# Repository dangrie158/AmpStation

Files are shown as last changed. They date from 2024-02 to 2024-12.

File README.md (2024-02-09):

# Class D Amplifier Project

This project aims to repurpose an old Teufel Decoder Station Case by building a Class D amplifier inside it.

## Introduction

The old Teufel Decoder Station Case has been transformed into a powerful Class D amplifier in this project.

## Features

- Compact design that fits perfectly into the Teufel Decoder Station Case
- High-efficiency Class D amplifier technology
- Excellent audio quality with low distortion
- Multiple input options for versatile connectivity
- Built-in protection circuitry for safe operation

This project is licensed under the [MIT License](LICENSE).

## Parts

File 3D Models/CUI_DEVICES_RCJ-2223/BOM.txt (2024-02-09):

3DX_CUI_DEVICES_Supplier: CUI Devices
3DX_CUI_DEVICES_Description: RCJ-22 Series, Input 1: Red, Input 2: White
3DX_CUI_DEVICES_Model Number: RCJ-2223

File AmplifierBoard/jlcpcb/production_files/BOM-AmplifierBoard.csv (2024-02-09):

Comment | Designator | Footprint | LCSC
10µH | L10,L11,L12,L13,L14,L15,L16,L17,L18,L19,L20,L21,L6,L7,L8,L9 | L_0805_2012Metric_Pad1.15x1.40mm_HandSolder | C1046
30pF | C97 | C_0805_2012Metric_Pad1.18x1.45mm_HandSolder | C107114
22µF | C40 | C_1206_3216Metric_Pad1.33x1.80mm_HandSolder | C12891
470pF | C42,C43,C46,C47 | C_0603_1608Metric_Pad1.08x0.95mm_HandSolder | C1620
18pF | C53,C54 | C_0603_1608Metric_Pad1.08x0.95mm_HandSolder | C1647
33nF | C15,C16 | C_Rect_L7.2mm_W2.5mm_P5.00mm_FKS2_FKP2_MKS2_MKP2 | C1739
100pF | C93,C94,C95,C96 | C_0805_2012Metric_Pad1.18x1.45mm_HandSolder | C1790
0 | R43,R46 | R_0603_1608Metric_Pad0.98x0.95mm_HandSolder | C21189
1k | R47,R48,R49,R50,R51,R52 | R_0603_1608Metric_Pad0.98x0.95mm_HandSolder | C21190
3k3 | R13,R14,R17,R18 | R_0603_1608Metric_Pad0.98x0.95mm_HandSolder | C22978
4k7 | R1,R2,R55,R56 | R_0603_1608Metric_Pad0.98x0.95mm_HandSolder | C23162
680 | R11,R12,R19,R20 | R_0603_1608Metric_Pad0.98x0.95mm_HandSolder | C23228
22 | R21,R22,R23,R24 | R_0603_1608Metric_Pad0.98x0.95mm_HandSolder | C23345
100k | R30,R31,R32,R33,R34,R35,R36,R37,R38,R39,R40,R41,R57,R58 | R_0603_1608Metric_Pad0.98x0.95mm_HandSolder | C25803
10k | R25,R26,R27,R28,R29,R42,R44,R45,R53,R54,R8 | R_0603_1608Metric_Pad0.98x0.95mm_HandSolder | C25804
100nF | C10,C12,C13,C14,C35,C36,C37,C38,C49,C50,C52,C55,C56,C58,C60,C61,C62,C63,C64,C66,C67,C68,C69,C70,C72,C73,C77,C78,C80,C81,C84,C85,C88,C89,C91,C92 | C_0805_2012Metric_Pad1.18x1.45mm_HandSolder | C28233
1µF 50V | C1,C2,C4,C44,C5,C7,C8 | C_0805_2012Metric_Pad1.18x1.45mm_HandSolder | C28323
22k | R7 | R_0603_1608Metric_Pad0.98x0.95mm_HandSolder | C31850
1.8k | R10,R15,R16,R9 | R_0603_1608Metric_Pad0.98x0.95mm_HandSolder | C4177
74HC14 | U17 | SOIC-14_3.9x8.7mm_P1.27mm | C5605
10µF | C83 | CP_EIA-3216-18_Kemet-A_Pad1.58x1.35mm_HandSolder | C7171
LM358 | U16 | SOIC-8_5.23x5.23mm_P1.27mm | C7950
1N4148 | D2,D3 | D_SOD-123 | C81598
12MHz | Y1 | Crystal_SMD_3225-4Pin_3.2x2.5mm_HandSoldering | C9002
~ | H2 | 3.2mm Hole Oblong
~ | H1 | 3.2mm Hole Oblong
~ | H4 | 3.2mm Hole Oblong
~ | H3 | 3.2mm Hole Oblong
1µ | C26 | C_Rect_L10.3mm_W5.0mm_P7.50mm_MKS4
AUX1 | J3 | RCJ-2223
1µ | C25 | C_Rect_L10.3mm_W5.0mm_P7.50mm_MKS4
10n | C29 | C_Rect_L7.2mm_W2.5mm_P5.00mm_FKS2_FKP2_MKS2_MKP2
LM1117MP-3.3 | U10 | SOT-223-3_TabPin2
LM833 | U11 | SOIC-8_5.23x5.23mm_P1.27mm
Heatsink | HS5 | ASS_0871_HS
1n | C27 | C_Rect_L7.2mm_W2.5mm_P5.00mm_FKS2_FKP2_MKS2_MKP2
10µH | L4 | L_12x12mm_H4.5mm
12-20V | J1 | BarrelJack_CLIFF_FC681465S_SMT_Horizontal
10µF | C31 | CP_Elec_4x5.4
1N5822 | D1 | D_DO-201AD_P15.24mm_Horizontal
Bypass | JP3 | SolderJumper-2_P1.3mm_Open_RoundedPad1.0x1.5mm
1n | C20 | C_Rect_L7.2mm_W2.5mm_P5.00mm_FKS2_FKP2_MKS2_MKP2
33nF | C24 | C_Rect_L7.2mm_W2.5mm_P5.00mm_FKS2_FKP2_MKS2_MKP2
Digital | J2 | FCR684205R
Heatsink | HS1 | ATS-CPX045045010-197-C1-R0
AUX2 | J4 | RCJ-2223
MIC811TUY | U8 | SOT-143
1n | C19 | C_Rect_L7.2mm_W2.5mm_P5.00mm_FKS2_FKP2_MKS2_MKP2
L7809 | U14 | TO-220-3_Vertical
10µF | C32 | CP_Elec_4x5.4
50k | RV2 | Potentiometer_Bourns_3296W_Vertical
10n | C22 | C_Rect_L7.2mm_W2.5mm_P5.00mm_FKS2_FKP2_MKS2_MKP2
PCM1793 | U5 | SSOP-28_5.3x10.2mm_P0.65mm
Fiducial | FID3 | Fiducial_1.5mm_Mask3mm
CHANNEL A | J5 | PhoenixContact_MSTBVA_2,5_2-G_1x02_P5.00mm_Vertical
WM8804 | U6 | SSOP-20_5.3x7.2mm_P0.65mm
10µF | C76 | CP_EIA-3216-18_Kemet-A_Pad1.58x1.35mm_HandSolder
10µF | C59 | CP_EIA-3216-18_Kemet-A_Pad1.58x1.35mm_HandSolder
50k | RV1 | Potentiometer_Bourns_3296W_Vertical
10µF | C57 | CP_EIA-3216-18_Kemet-A_Pad1.58x1.35mm_HandSolder
3R3 | R5 | R_1206_3216Metric_Pad1.30x1.75mm_HandSolder
10µF | C90 | CP_EIA-3216-18_Kemet-A_Pad1.58x1.35mm_HandSolder
Fiducial | FID1 | Fiducial_1.5mm_Mask3mm
10µF | C75 | CP_Elec_4x5.4
Bypass | JP2 | SolderJumper-2_P1.3mm_Open_RoundedPad1.0x1.5mm
10n | C21 | C_Rect_L7.2mm_W2.5mm_P5.00mm_FKS2_FKP2_MKS2_MKP2
L7805 | U3 | TO-220-3_Vertical
10µF | C86 | CP_EIA-3216-18_Kemet-A_Pad1.58x1.35mm_HandSolder
PT2258 | U12 | SO-20_12.8x7.5mm_P1.27mm
10µF | C99 | CP_Elec_4x5.4
3R3 | R4 | R_1206_3216Metric_Pad1.30x1.75mm_HandSolder
Bypass | JP5 | SolderJumper-2_P1.3mm_Open_RoundedPad1.0x1.5mm
10µH | L2 | L_12x12mm_H4.5mm
L7812 | U2 | TO-220-3_Vertical
1800pF | C45 | C_Rect_L7.2mm_W2.5mm_P5.00mm_FKS2_FKP2_MKS2_MKP2
10µF | C87 | CP_EIA-3216-18_Kemet-A_Pad1.58x1.35mm_HandSolder
10µF | C48 | CP_EIA-3216-18_Kemet-A_Pad1.58x1.35mm_HandSolder
1µ | C17 | C_Rect_L10.3mm_W5.0mm_P7.50mm_MKS4
Fiducial | FID2 | Fiducial_1.5mm_Mask3mm
Serial Debug | J9 | PinHeader_1x03_P2.54mm_Vertical
10µF | C51 | CP_EIA-3216-18_Kemet-A_Pad1.58x1.35mm_HandSolder
470µF 50V | C6 | CP_Elec_16x17.5
10µF | C100 | CP_Elec_4x5.4
LM2576S-12 | U4 | TO-263-5_TabPin3
10µF | C34 | CP_Elec_4x5.4
Bypass | JP4 | SolderJumper-2_P1.3mm_Open_RoundedPad1.0x1.5mm
1µ | C18 | C_Rect_L10.3mm_W5.0mm_P7.50mm_MKS4
Frontpanel | J7 | PCB-C-20-T-SMT
10µF | C71 | CP_Elec_4x5.4
Heatsink | HS2 | ASS_0871_HS
LM833 | U13 | SOIC-8_5.23x5.23mm_P1.27mm
LM833 | U7 | SOIC-8_5.23x5.23mm_P1.27mm
100µF 50V | C39 | CP_Elec_8x10
33nF | C23 | C_Rect_L7.2mm_W2.5mm_P5.00mm_FKS2_FKP2_MKS2_MKP2
470µF 16V | C11 | CP_Elec_10x10.5
10µF | C33 | CP_Elec_4x5.4
1n | C28 | C_Rect_L7.2mm_W2.5mm_P5.00mm_FKS2_FKP2_MKS2_MKP2
10µF | C65 | CP_Elec_4x5.4
1800pF | C41 | C_Rect_L7.2mm_W2.5mm_P5.00mm_FKS2_FKP2_MKS2_MKP2
CHANNEL B | J6 | PhoenixContact_MSTBVA_2,5_2-G_1x02_P5.00mm_Vertical
ICSP | J8 | IDC-Header_2x03_P2.54mm_Vertical
68µH | L5 | L_12x12mm_H4.5mm
L7905 | U9 | TO-220-3_Vertical
10n | C30 | C_Rect_L7.2mm_W2.5mm_P5.00mm_FKS2_FKP2_MKS2_MKP2
10µF | C74 | CP_Elec_4x5.4
470µF 50V | C3 | CP_Elec_16x17.5
10µF | C82 | CP_EIA-3216-18_Kemet-A_Pad1.58x1.35mm_HandSolder
ATmega328PB-A | U18 | TQFP-32_7x7mm_P0.8mm
10µH | L1 | L_12x12mm_H4.5mm
10µH | L3 | L_12x12mm_H4.5mm
LM833 | U15 | SOIC-8_5.23x5.23mm_P1.27mm
100µF 50V | C98 | CP_Elec_8x10
TPA3251 | U1 | HTSSOP-44_6.1x14mm_P0.635mm_TopEP4.14x7.01mm
10µF | C79 | CP_EIA-3216-18_Kemet-A_Pad1.58x1.35mm_HandSolder
Star Ground | JP6 | SolderJumper-2_P1.3mm_Bridged2Bar_RoundedPad1.0x1.5mm
Star Ground | JP1 | SolderJumper-2_P1.3mm_Bridged2Bar_RoundedPad1.0x1.5mm
3R3 | R6 | R_1206_3216Metric_Pad1.30x1.75mm_HandSolder
3R3 | R3 | R_1206_3216Metric_Pad1.30x1.75mm_HandSolder
10nF | C9 | C_0805_2012Metric_Pad1.18x1.45mm_HandSolder

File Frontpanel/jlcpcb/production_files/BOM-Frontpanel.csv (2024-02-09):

Comment | Designator | Footprint | LCSC
~ | J4 | RCJ-2223
~ | J3 | RCJ-2223
~ | J2 | NC3FDL-1
~ | J1 | NC3FDL-1
MountingHole_Pad | H4 | MountingHole_3.2mm_M3_DIN965_Pad
MountingHole_Pad | H1 | MountingHole_3.2mm_M3_DIN965_Pad
MountingHole_Pad | H2 | MountingHole_3.2mm_M3_DIN965_Pad
MountingHole_Pad | H3 | MountingHole_3.2mm_M3_DIN965_Pad

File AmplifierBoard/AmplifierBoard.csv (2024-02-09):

Source: | /Users/griesshaber/src/Hardware/AmpStation/AmplifierBoard/AmplifierBoard.kicad_sch
Date: | 2024 February 06, Tuesday 09:46:08
Tool: | Eeschema 7.0.5-0
Generator: | /Applications/KiCad/KiCad.app/Contents/SharedSupport/plugins/bom_csv_grouped_by_value_with_fp.py
Component Count: | 228
Ref | Qnty | Value | Cmp name | Footprint | Description | Vendor | DNP
C1, C2, C4, C5 | 4 | 1µF 50V | C_Small | Capacitor_SMD:C_0805_2012Metric_Pad1.18x1.45mm_HandSolder | Unpolarized capacitor, small symbol
C3, C6 | 2 | 470µF 50V | C_Polarized_Small | Capacitor_SMD:CP_Elec_16x17.5 | Polarized capacitor, small symbol
C7, C8 | 2 | 1µF | C_Small | Capacitor_SMD:C_0805_2012Metric_Pad1.18x1.45mm_HandSolder | Unpolarized capacitor, small symbol
C9 | 1 | 10nF | C_Small | Capacitor_SMD:C_0805_2012Metric_Pad1.18x1.45mm_HandSolder | Unpolarized capacitor, small symbol
C10, C35, C36, C37, C38, C49, C50, C52, C55, C56, C58, C60, C61, C62, C63, C64, C66, C67, C68, C69, C70, C72, C73, C77, C78, C80, C81, C84, C85, C88, C89, C91, C92 | 33 | 100nF | C_Small | Capacitor_SMD:C_0805_2012Metric_Pad1.18x1.45mm_HandSolder | Unpolarized capacitor, small symbol
C11 | 1 | 470µF 16V | C_Polarized_Small | Capacitor_SMD:CP_Elec_10x10.5 | Polarized capacitor, small symbol
C12, C13 | 2 | 100n | C_Small | Capacitor_SMD:C_0805_2012Metric_Pad1.18x1.45mm_HandSolder | Unpolarized capacitor, small symbol
C14 | 1 | 100nF 16V | C_Small | Capacitor_SMD:C_0805_2012Metric_Pad1.18x1.45mm_HandSolder | Unpolarized capacitor, small symbol
C15, C16, C23, C24 | 4 | 33nF | C_Small | Capacitor_THT:C_Rect_L7.2mm_W2.5mm_P5.00mm_FKS2_FKP2_MKS2_MKP2 | Unpolarized capacitor, small symbol
C17, C18, C25, C26 | 4 | 1µ | C_Small | Capacitor_THT:C_Rect_L10.3mm_W5.0mm_P7.50mm_MKS4 | Unpolarized capacitor, small symbol
C19, C20, C27, C28 | 4 | 1n | C_Small | Capacitor_THT:C_Rect_L7.2mm_W2.5mm_P5.00mm_FKS2_FKP2_MKS2_MKP2 | Unpolarized capacitor, small symbol
C21, C22, C29, C30 | 4 | 10n | C_Small | Capacitor_THT:C_Rect_L7.2mm_W2.5mm_P5.00mm_FKS2_FKP2_MKS2_MKP2 | Unpolarized capacitor, small symbol
C31, C32, C33, C34, C65, C71, C74, C75, C99, C100 | 10 | 10µF | C_Small | Capacitor_SMD:CP_Elec_4x5.4 | Unpolarized capacitor, small symbol
C39, C98 | 2 | 100µF 50V | C_Polarized_Small | Capacitor_SMD:CP_Elec_8x10 | Polarized capacitor, small symbol
C40 | 1 | 22µF | C_Small | Capacitor_SMD:C_1206_3216Metric_Pad1.33x1.80mm_HandSolder | Unpolarized capacitor, small symbol
C41, C45 | 2 | 1800pF | C_Small | Capacitor_THT:C_Rect_L7.2mm_W2.5mm_P5.00mm_FKS2_FKP2_MKS2_MKP2 | Unpolarized capacitor, small symbol
C42, C43, C46, C47 | 4 | 470pF | C_Small | Capacitor_SMD:C_0603_1608Metric_Pad1.08x0.95mm_HandSolder | Unpolarized capacitor, small symbol
C44 | 1 | 1µ | C_Small | Capacitor_SMD:C_0805_2012Metric_Pad1.18x1.45mm_HandSolder | Unpolarized capacitor, small symbol
C48, C51, C57, C59, C76, C79, C82, C83, C86, C87, C90 | 11 | 10µF | C_Polarized_Small | Capacitor_Tantalum_SMD:CP_EIA-3216-18_Kemet-A_Pad1.58x1.35mm_HandSolder | Polarized capacitor, small symbol
C53, C54 | 2 | 18pF | C_Small | Capacitor_SMD:C_0603_1608Metric_Pad1.08x0.95mm_HandSolder | Unpolarized capacitor, small symbol
C93, C94, C95, C96 | 4 | 100pF | C_Small | Capacitor_SMD:C_0805_2012Metric_Pad1.18x1.45mm_HandSolder | Unpolarized capacitor, small symbol
C97 | 1 | 30pF | C_Small | Capacitor_SMD:C_0805_2012Metric_Pad1.18x1.45mm_HandSolder | Unpolarized capacitor, small symbol
D1 | 1 | 1N5822 | 1N5822 | Diode_THT:D_DO-201AD_P15.24mm_Horizontal | 40V 3A Schottky Barrier Rectifier Diode, DO-201AD
D2, D3 | 2 | 1N4148 | 1N4148 | Diode_SMD:D_SOD-123 | 100V 0.15A standard switching diode, DO-35
FID1, FID2, FID3 | 3 | Fiducial | Fiducial | Fiducial:Fiducial_1.5mm_Mask3mm | Fiducial Marker
H1, H2, H3, H4 | 4 | ~ | MountingHole_Pad | CustomParts:3.2mm Hole Oblong | Mounting Hole with connection
HS1 | 1 | Heatsink | Heatsink | CustomParts:ATS-CPX045045010-197-C1-R0 | Heatsink
HS2, HS5 | 2 | Heatsink | Heatsink | CustomParts:ASS_0871_HS | Heatsink
J1 | 1 | 12-20V | Barrel_Jack_Switch | Connector_BarrelJack:BarrelJack_CLIFF_FC681465S_SMT_Horizontal | DC Barrel Jack with an internal switch
J2 | 1 | Digital | FCR684205R | CustomParts:FCR684205R
J3 | 1 | AUX1 | RCJ-22 | CustomParts:RCJ-2223 | double coaxial connector (BNC, SMA, SMB, SMC, Cinch/RCA, LEMO, ...)
J4 | 1 | AUX2 | RCJ-22 | CustomParts:RCJ-2223 | double coaxial connector (BNC, SMA, SMB, SMC, Cinch/RCA, LEMO, ...)
J5 | 1 | CHANNEL A | Conn_01x02_Pin | Connector_Phoenix_MSTB:PhoenixContact_MSTBVA_2,5_2-G_1x02_P5.00mm_Vertical | Generic connector, single row, 01x02, script generated
J6 | 1 | CHANNEL B | Conn_01x02_Pin | Connector_Phoenix_MSTB:PhoenixContact_MSTBVA_2,5_2-G_1x02_P5.00mm_Vertical | Generic connector, single row, 01x02, script generated
J7 | 1 | Frontpanel | Conn_01x20_Socket | CustomParts:PCB-C-20-T-SMT | Generic connector, single row, 01x20, script generated
J8 | 1 | ICSP | Conn_02x03_Odd_Even | Connector_IDC:IDC-Header_2x03_P2.54mm_Vertical | Generic connector, double row, 02x03, odd/even pin numbering scheme (row 1 odd numbers, row 2 even numbers), script generated (kicad-library-utils/schlib/autogen/connector/)
J9 | 1 | Serial Debug | Conn_01x03 | Connector_PinHeader_2.54mm:PinHeader_1x03_P2.54mm_Vertical | Generic connector, single row, 01x03, script generated (kicad-library-utils/schlib/autogen/connector/)
JP1, JP6 | 2 | Star Ground | Jumper_2_Bridged | Jumper:SolderJumper-2_P1.3mm_Bridged2Bar_RoundedPad1.0x1.5mm | Jumper, 2-pole, closed/bridged
JP2, JP3, JP4, JP5 | 4 | Bypass | Jumper_2_Open | Jumper:SolderJumper-2_P1.3mm_Open_RoundedPad1.0x1.5mm | Jumper, 2-pole, open
L1, L2, L3, L4 | 4 | 10µH | L | Inductor_SMD:L_12x12mm_H4.5mm | Inductor
L5 | 1 | 68µH | L | Inductor_SMD:L_12x12mm_H4.5mm | Inductor
L6, L7, L8, L9, L10, L11, L12, L13, L14, L15, L16, L17, L18, L19, L20, L21 | 16 | 10µH | L_Small | Inductor_SMD:L_0805_2012Metric_Pad1.15x1.40mm_HandSolder | Inductor, small symbol
R1, R2, R55, R56 | 4 | 4k7 | R_Small | Resistor_SMD:R_0603_1608Metric_Pad0.98x0.95mm_HandSolder | Resistor, small symbol
R3, R4, R5, R6 | 4 | 3R3 | R_Small | Resistor_SMD:R_1206_3216Metric_Pad1.30x1.75mm_HandSolder | Resistor, small symbol
R7 | 1 | 22k | R_Small | Resistor_SMD:R_0603_1608Metric_Pad0.98x0.95mm_HandSolder | Resistor, small symbol
R8, R25, R26, R27, R28, R29, R42, R44, R45, R53, R54 | 11 | 10k | R_Small | Resistor_SMD:R_0603_1608Metric_Pad0.98x0.95mm_HandSolder | Resistor, small symbol
R9, R10, R15, R16 | 4 | 1.8k | R_Small | Resistor_SMD:R_0603_1608Metric_Pad0.98x0.95mm_HandSolder | Resistor, small symbol
R11, R12, R19, R20 | 4 | 680 | R_Small | Resistor_SMD:R_0603_1608Metric_Pad0.98x0.95mm_HandSolder | Resistor, small symbol
R13, R14, R17, R18 | 4 | 3k3 | R_Small | Resistor_SMD:R_0603_1608Metric_Pad0.98x0.95mm_HandSolder | Resistor, small symbol
R21, R22, R23, R24 | 4 | 22 | R_Small | Resistor_SMD:R_0603_1608Metric_Pad0.98x0.95mm_HandSolder | Resistor, small symbol
R30, R31, R32, R33, R34, R35, R36, R37, R38, R39, R40, R41, R57, R58 | 14 | 100k | R_Small | Resistor_SMD:R_0603_1608Metric_Pad0.98x0.95mm_HandSolder | Resistor, small symbol
R43, R46 | 2 | 0 | R_Small | Resistor_SMD:R_0603_1608Metric_Pad0.98x0.95mm_HandSolder | Resistor, small symbol
R47, R48, R49, R50, R51, R52 | 6 | 1k | R_Small | Resistor_SMD:R_0603_1608Metric_Pad0.98x0.95mm_HandSolder | Resistor, small symbol
RV1, RV2 | 2 | 50k | R_Potentiometer_Small | Potentiometer_THT:Potentiometer_Bourns_3296W_Vertical | Potentiometer
U1 | 1 | TPA3251 | TPA3251 | Package_SO:HTSSOP-44_6.1x14mm_P0.635mm_TopEP4.14x7.01mm | 175-W Stereo, 350-W Mono PurePath Ultra-HD Analog-Input Class-D Amplifier, HTSSOP-44
U2 | 1 | L7812 | L7812 | Package_TO_SOT_THT:TO-220-3_Vertical | Positive 1.5A 35V Linear Regulator, Fixed Output 12V, TO-220/TO-263/TO-252
U3 | 1 | L7805 | L7805 | Package_TO_SOT_THT:TO-220-3_Vertical | Positive 1.5A 35V Linear Regulator, Fixed Output 5V, TO-220/TO-263/TO-252
U4 | 1 | LM2576S-12 | LM2576S-12 | Package_TO_SOT_SMD:TO-263-5_TabPin3 | 12V, 3A SIMPLE SWITCHER® Step-Down Voltage Regulator, TO-263
U5 | 1 | PCM1793 | PCM1793 | Package_SO:SSOP-28_5.3x10.2mm_P0.65mm
U6 | 1 | WM8804 | WM8804 | Package_SO:SSOP-20_5.3x7.2mm_P0.65mm
U7, U11, U13, U15 | 4 | LM833 | OPA2134 | Package_SO:SOIC-8_5.23x5.23mm_P1.27mm | Dual SoundPlus High Performance Audio Operational Amplifiers, DIP-8/SOIC-8
U8 | 1 | MIC811TUY | MIC811TUY | Package_TO_SOT_SMD:SOT-143 | Power supply supervisor, Manual reset, Threshold 3.08V, SOT-143
U9 | 1 | L7905 | L7905 | Package_TO_SOT_THT:TO-220-3_Vertical | Negative 1.5A 35V Linear Regulator, Fixed Output -5V, TO-220/TO-263
U10 | 1 | LM1117MP-3.3 | LM1117MP-3.3 | Package_TO_SOT_SMD:SOT-223-3_TabPin2 | 800mA Low-Dropout Linear Regulator, 3.3V fixed output, SOT-223
U12 | 1 | PT2258 | PT2258 | Package_SO:SO-20_12.8x7.5mm_P1.27mm
U14 | 1 | L7809 | L7809 | Package_TO_SOT_THT:TO-220-3_Vertical | Positive 1.5A 35V Linear Regulator, Fixed Output 9V, TO-220/TO-263/TO-252
U16 | 1 | LM358 | LM358 | Package_SO:SOIC-8_5.23x5.23mm_P1.27mm | Low-Power, Dual Operational Amplifiers, DIP-8/SOIC-8/TO-99-8
U17 | 1 | 74HC14 | 74HC14 | Package_SO:SOIC-14_3.9x8.7mm_P1.27mm | Hex inverter schmitt trigger
U18 | 1 | ATmega328PB-A | ATmega328PB-A | Package_QFP:TQFP-32_7x7mm_P0.8mm | 20MHz, 32kB Flash, 2kB SRAM, 1kB EEPROM, TQFP-32
Y1 | 1 | 12MHz | Crystal_GND24_Small | Crystal:Crystal_SMD_3225-4Pin_3.2x2.5mm_HandSoldering | Four pin crystal, GND on pins 2 and 4, small symbol

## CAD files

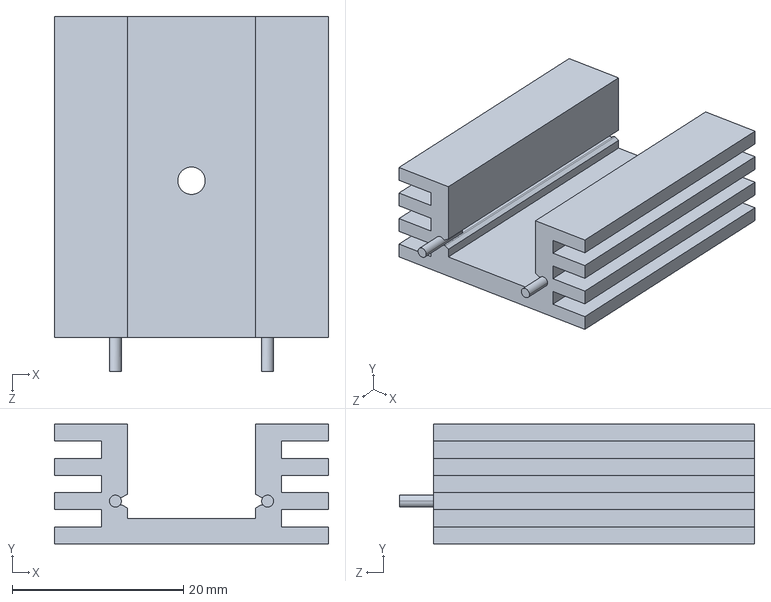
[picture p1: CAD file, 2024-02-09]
3D Models/ASSMANN-v5229x/V5229X.STEP
32.0 x 14.0 x 41.5 mm

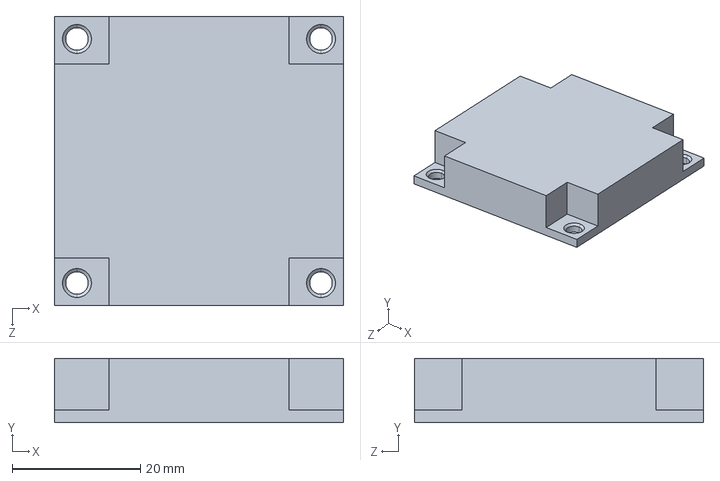
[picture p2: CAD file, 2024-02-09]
3D Models/ATS-CPX-197-CX-R0_FUSED/ATS-CPX-197-CX-R0_FUSED.STEP
45.0 x 10.0 x 45.0 mm

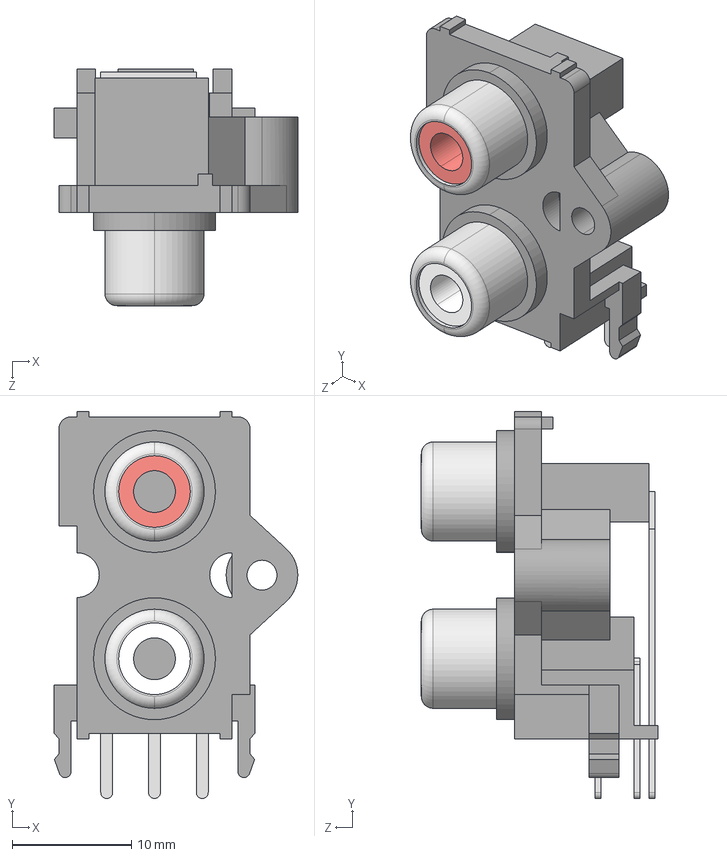
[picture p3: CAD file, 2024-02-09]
3D Models/CUI_DEVICES_RCJ-2223/CUI_DEVICES_RCJ-2223.step
20.4 x 32.4 x 19.8 mm
RCJ-22_RCJ-22XX
PLUG_Red
PLUG_White

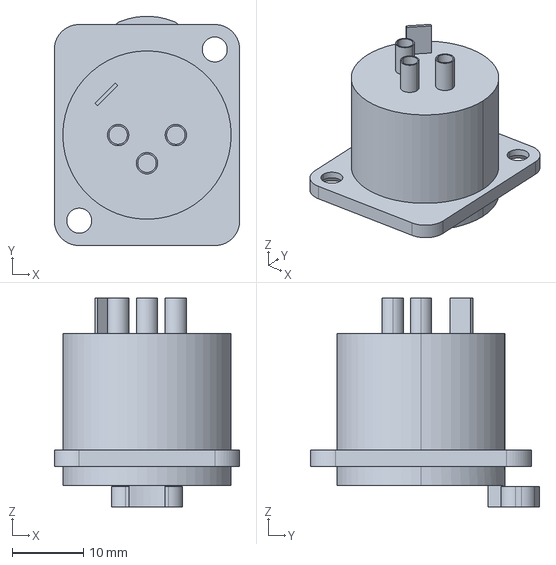
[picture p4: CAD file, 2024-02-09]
Frontpanel/CustomParts.3d/NC3FD-L-1.stp
26.0 x 32.1 x 29.3 mm

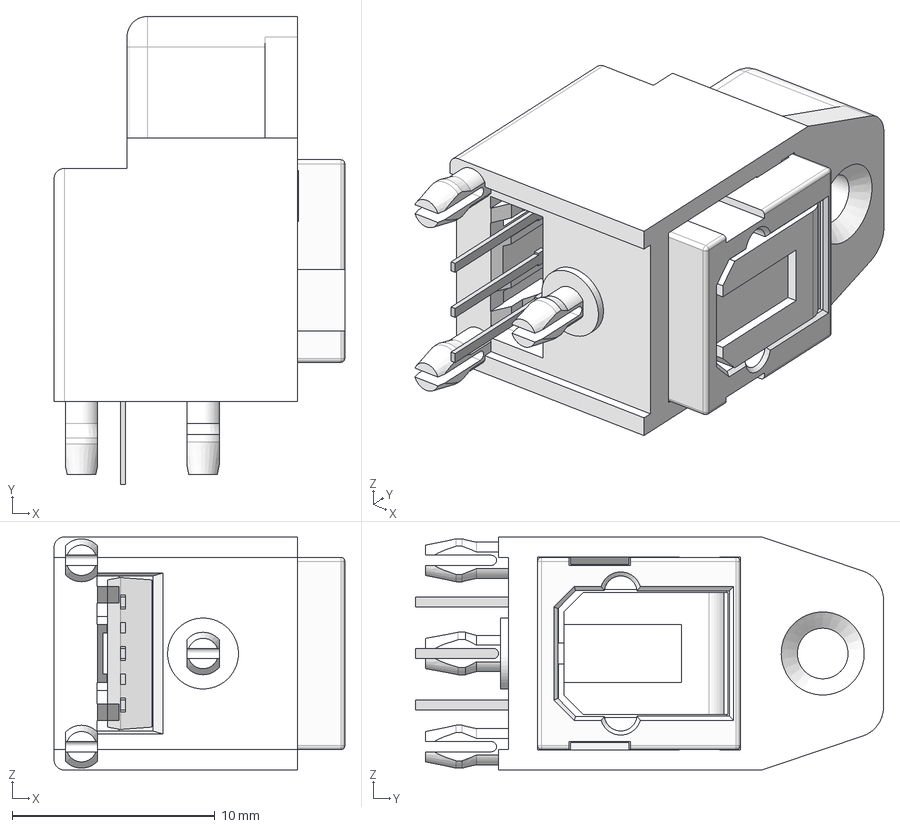
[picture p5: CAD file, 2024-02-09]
3D Models/FCR684205R/FCR684205R ORJ5.STEP
14.4 x 23.1 x 11.5 mm

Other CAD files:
3D Models/ASSMANN-v5229x/v5229x.stl
3D Models/CUI_DEVICES_RCJ-2223/CUI_DEVICES_RCJ-2223.STL

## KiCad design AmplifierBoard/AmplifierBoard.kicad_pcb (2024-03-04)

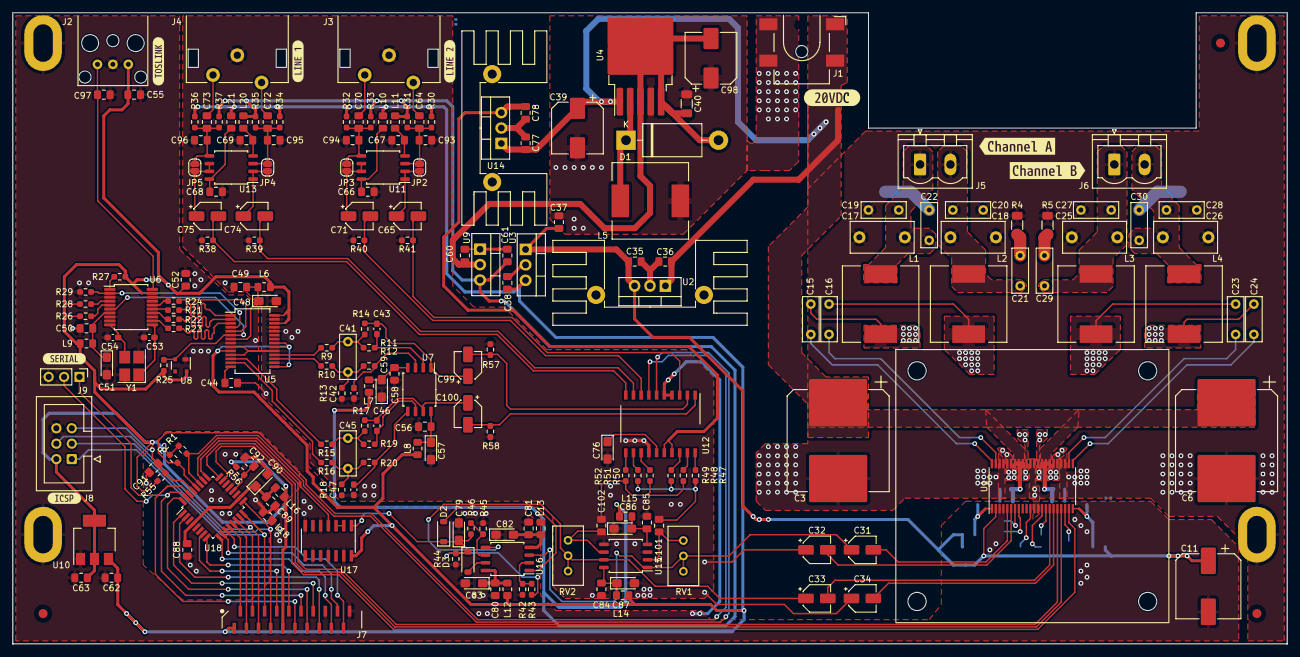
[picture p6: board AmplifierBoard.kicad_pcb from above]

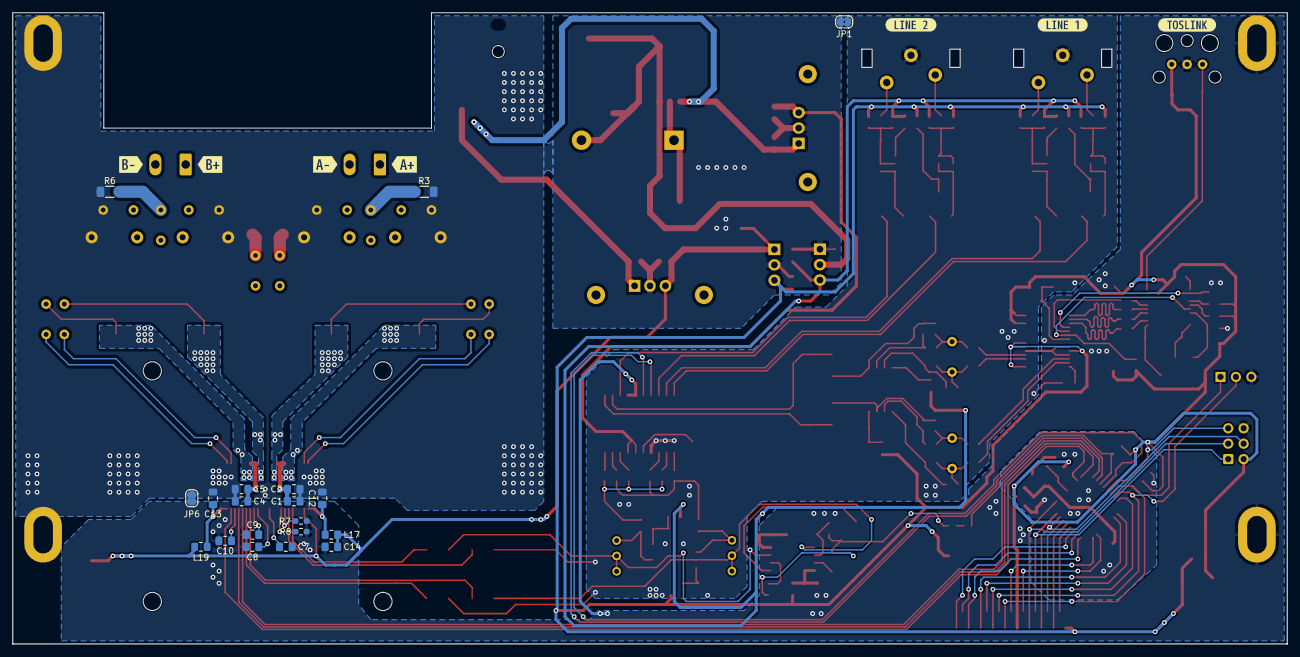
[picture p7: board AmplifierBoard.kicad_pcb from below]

Board: 2 copper layers, 210.0 x 104.0 mm, 243 parts (26 on the bottom side), 145 nets.

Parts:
C1, C2, C4, C5: 1µF 50V; C_0805_2012Metric_Pad1.18x1.45mm_HandSolder
C3, C6: 470µF 50V; CP_Elec_16x17.5
C7, C8: 1µF; C_0805_2012Metric_Pad1.18x1.45mm_HandSolder
C9: 10nF; C_0805_2012Metric_Pad1.18x1.45mm_HandSolder
C10, C35, C36, C37, C38, C49, C50, C52, C55, C56, C58, C60, C61, C62, C63, C64, C66, C67, C68, C69, C70, C72, C73, C77, C78, C80, C81, C84, C85, C88, C89, C91, C92: 100nF; C_0805_2012Metric_Pad1.18x1.45mm_HandSolder
C11: 470µF 16V; CP_Elec_10x10.5
C12, C13: 100n; C_0805_2012Metric_Pad1.18x1.45mm_HandSolder
C14: 100nF 16V; C_0805_2012Metric_Pad1.18x1.45mm_HandSolder
C15, C16, C23, C24: 33nF; C_Rect_L7.2mm_W2.5mm_P5.00mm_FKS2_FKP2_MKS2_MKP2
C17, C18, C25, C26: 1µ; C_Rect_L10.3mm_W5.0mm_P7.50mm_MKS4
C19, C20, C27, C28: 1n; C_Rect_L7.2mm_W2.5mm_P5.00mm_FKS2_FKP2_MKS2_MKP2
C21, C22, C29, C30: 10n; C_Rect_L7.2mm_W2.5mm_P5.00mm_FKS2_FKP2_MKS2_MKP2
C31, C32, C33, C34, C65, C71, C74, C75, C99, C100: 10µF; CP_Elec_4x5.4
C39, C98: 100µF 50V; CP_Elec_8x10
C40: 22µF; C_1206_3216Metric_Pad1.33x1.80mm_HandSolder
C41, C45: 1800pF; C_Rect_L7.2mm_W2.5mm_P5.00mm_FKS2_FKP2_MKS2_MKP2
C42, C43, C46, C47: 470pF; C_0603_1608Metric_Pad1.08x0.95mm_HandSolder
C44: 1µ; C_0805_2012Metric_Pad1.18x1.45mm_HandSolder
C48, C51, C57, C59, C76, C79, C82, C83, C86, C87, C90: 10µF; CP_EIA-3216-18_Kemet-A_Pad1.58x1.35mm_HandSolder
C53, C54: 18pF; C_0603_1608Metric_Pad1.08x0.95mm_HandSolder
C93, C94, C95, C96: 100pF; C_0805_2012Metric_Pad1.18x1.45mm_HandSolder
C97: 30pF; C_0805_2012Metric_Pad1.18x1.45mm_HandSolder
C101, C102: 10µF; C_0805_2012Metric_Pad1.18x1.45mm_HandSolder
D1: 1N5822; D_DO-201AD_P15.24mm_Horizontal
D2, D3: 1N4148; D_SOD-123
FID1, FID2, FID3: Fiducial; Fiducial_1.5mm_Mask3mm
H1, H2, H3, H4: 3.2mm Hole Oblong
HS1: Heatsink; ATS-CPX045045010-197-C1-R0
HS2, HS5: Heatsink; ASS_0871_HS
J1: 12-20V; BarrelJack_CLIFF_FC681465S_SMT_Horizontal
J2: Digital; FCR684205R
J3: AUX1; RCJ-2223
J4: AUX2; RCJ-2223
J5: CHANNEL A; PhoenixContact_MSTBVA_2,5_2-G_1x02_P5.00mm_Vertical
J6: CHANNEL B; PhoenixContact_MSTBVA_2,5_2-G_1x02_P5.00mm_Vertical
J7: Frontpanel; PCB-C-20-T-SMT
J8: ICSP; IDC-Header_2x03_P2.54mm_Vertical
J9: Serial Debug; PinHeader_1x03_P2.54mm_Vertical
JP1, JP6: Star Ground; SolderJumper-2_P1.3mm_Bridged2Bar_RoundedPad1.0x1.5mm
JP2, JP3, JP4, JP5: Bypass; SolderJumper-2_P1.3mm_Open_RoundedPad1.0x1.5mm
L1, L2, L3, L4: 10µH; L_12x12mm_H4.5mm
L5: 68µH; L_12x12mm_H4.5mm
L6, L7, L8, L9, L10, L11, L12, L13, L14, L15, L16, L17, L18, L19, L20, L21: 10µH; L_0805_2012Metric_Pad1.15x1.40mm_HandSolder
R1, R2, R55, R56: 4k7; R_0603_1608Metric_Pad0.98x0.95mm_HandSolder
R3, R4, R5, R6: 3R3; R_1206_3216Metric_Pad1.30x1.75mm_HandSolder
R7: 27k; R_0603_1608Metric_Pad0.98x0.95mm_HandSolder
R8, R25, R26, R27, R28, R29, R43, R44, R46: 10k; R_0603_1608Metric_Pad0.98x0.95mm_HandSolder
R9, R10, R15, R16: 1.8k; R_0603_1608Metric_Pad0.98x0.95mm_HandSolder
R11, R12, R19, R20: 680; R_0603_1608Metric_Pad0.98x0.95mm_HandSolder
R13, R14, R17, R18: 3k3; R_0603_1608Metric_Pad0.98x0.95mm_HandSolder
R21, R22, R23, R24: 22; R_0603_1608Metric_Pad0.98x0.95mm_HandSolder
R30, R31, R32, R33, R34, R35, R36, R37, R38, R39, R40, R41, R57, R58: 100k; R_0603_1608Metric_Pad0.98x0.95mm_HandSolder
R42, R45: 0; R_0603_1608Metric_Pad0.98x0.95mm_HandSolder
R47, R48, R49, R50, R51, R52: 1k; R_0603_1608Metric_Pad0.98x0.95mm_HandSolder
RV1, RV2: 50k; Potentiometer_Bourns_3296W_Vertical
U1: TPA3251; HTSSOP-44_6.1x14mm_P0.635mm_TopEP4.14x7.01mm
U2: L7812; TO-220-3_Vertical
U3: L7805; TO-220-3_Vertical
U4: LM2576S-12; TO-263-5_TabPin3
U5: PCM1793; SSOP-28_5.3x10.2mm_P0.65mm
U6: WM8804; SSOP-20_5.3x7.2mm_P0.65mm
U7, U11, U13, U15: LM833; SOIC-8_5.23x5.23mm_P1.27mm
U8: MIC811TUY; SOT-143
U9: L7905; TO-220-3_Vertical
U10: LM1117MP-3.3; SOT-223-3_TabPin2
U12: PT2258; SO-20_12.8x7.5mm_P1.27mm
U14: L7809; TO-220-3_Vertical
U16: LM358; SOIC-8_5.23x5.23mm_P1.27mm
U17: 74HC14; SOIC-14_3.9x8.7mm_P1.27mm
U18: ATmega328PB-A; TQFP-32_7x7mm_P0.8mm
Y1: 12MHz; Crystal_SMD_3225-4Pin_3.2x2.5mm_HandSoldering
kibuzzard-65BCF8D4: G***; kibuzzard-65BCF8D4
kibuzzard-65BCF90F: G***; kibuzzard-65BCF90F
kibuzzard-65BCFB63: G***; kibuzzard-65BCFB63
kibuzzard-65BCFB77: G***; kibuzzard-65BCFB77
kibuzzard-65BCFB90: G***; kibuzzard-65BCFB90
kibuzzard-65BCFBA1: G***; kibuzzard-65BCFBA1
kibuzzard-65BD00A1: G***; kibuzzard-65BD00A1
kibuzzard-65BD00A6: G***; kibuzzard-65BD00A6
kibuzzard-65BD000D: G***; kibuzzard-65BD000D
kibuzzard-65BD0ED3: G***; kibuzzard-65BD0ED3
kibuzzard-65BD00F0: G***; kibuzzard-65BD00F0
kibuzzard-65BD0F18: G***; kibuzzard-65BD0F18
kibuzzard-65BD008D: G***; kibuzzard-65BD008D
kibuzzard-65BD0105: G***; kibuzzard-65BD0105
kibuzzard-65BD0157: G***; kibuzzard-65BD0157

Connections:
+3V3: C52.1, C55.1, C63.1, J2.3 (VCC), J7.9, J8.2, L6.1, L9.1, L16.1, R1.1, R2.1, R25.1, R26.1, R27.1, R28.1, R55.2, R56.2, U5.26 (FMT0), U5.28 (FMT2), U6.19 (DVDD), U8.4 (VCC), U10.2 (VO)
+5V: C38.1, C62.1, J7.1, L8.1, L10.1, L12.1, L14.1, L21.1, R30.1, R32.1, R34.1, R36.1, U3.3 (OUT), U5.10 (VCCR), U5.15 (VCCC), U5.20 (VCCL), U5.21 (VCCF), U10.3 (VI), U17.14 (VCC)
+9V: C78.1, U12.16 (VCC), U12.17 (CODE1), U14.3 (OUT)
+12V: C11.1, C14.1, C35.1, C37.1, L17.1, L19.1, U1.2 (VDD), U2.3 (OUT), U3.1 (IN)
-5V: C61.2, L7.2, L11.2, L13.2, L15.2, L20.2, R31.2, R33.2, R35.2, R37.2, U9.3 (VO)
-12V: C40.2, C60.2, C98.2, D1.2 (A), U4.3 (GND), U4.5 (~ON/OFF), U9.2 (VI)
/AnalogBuffers/IN1: C64.1, J3.3 (IN1)
/AnalogBuffers/IN2: C70.1, J3.2 (IN2)
/AnalogBuffers/IN3: C72.1, J4.3 (IN1)
/AnalogBuffers/IN4: C73.1, J4.2 (IN2)
/AnalogBuffers/OUT1: C65.2, R41.1, U12.3 (IN3)
/AnalogBuffers/OUT2: C71.2, R40.1, U12.8 (IN4)
/AnalogBuffers/OUT3: C74.2, R39.1, U12.9 (IN5)
/AnalogBuffers/OUT4: C75.2, R38.1, U12.10 (IN6)
/MCU/MCUGND: C88.2, C89.2, C90.2, C91.1, C92.1, L18.1, U18.5 (GND), U18.21 (GND)
/MCU/MISO: J7.6, J8.1, U18.16 (PB4)
/MCU/MOSI: J7.5, J8.4, U18.15 (PB3)
/MCU/RXD: J7.11, J9.1, U18.30 (PD0)
/MCU/SCK: J7.7, J8.3, U18.17 (PB5)
/MCU/TXD: J7.12, J9.2, U18.31 (PD1)
/MCU/~RESET: C91.2, J8.5, R55.1, U18.29 (~RESET/PC6)
/PowerAmp/SPKA+: C17.1, C19.1, C22.1, J5.1, L1.2
/PowerAmp/SPKA-: C18.2, C20.2, C21.2, J5.2, L2.2
/PowerAmp/SPKB+: C25.1, C27.1, C29.1, J6.1, L3.2
/PowerAmp/SPKB-: C26.2, C28.2, C30.2, J6.2, L4.2
/TosLink DAC/ERR: R29.2, U5.4 (MUTE), U6.2 (GP0/SWIFM)
/TosLink DAC/LOUT: C99.2, R57.1, U12.2 (IN2)
/TosLink DAC/ROUT: C100.2, R58.1, U12.1 (IN1)
/TosLink DAC/RX: C97.1, J2.1 (Data), U6.20 (RX0)
/TosLink DAC/~RST: R25.2, U5.6 (~RST), U6.6 (RESETB), U8.2 (~RESET)
AMP_CLIP: U1.21 (~CLIP_OTW), U18.23 (PC0)
AMP_FAULT: U1.19 (~FAULT), U18.24 (PC1)
AMP_PWR: U1.18 (~RESET), U18.25 (PC2)
AUDIO_DETECT: U17.4, U18.26 (PC3)
GND: C1.2, C2.2, C3.2, C4.2, C5.2, C6.2, C12.2, C13.2, C17.2, C18.1, C19.2, C20.1, C25.2, C26.1, C27.2, C28.1, C35.2, C36.2, C37.2, C38.2, C39.2, C40.1, C60.1, C61.1, C77.2, C78.2, C98.1, H2.1, H4.1, J1.2, J1.3, JP1.1 (A), JP6.1 (A), L5.2, R3.1, R4.1, R5.1, R6.1, U1.12 (GND), U1.13 (GND), U1.25 (GND), U1.26 (GND), U1.33 (GND), U1.34 (GND), U1.41 (GND), U1.42 (GND), U2.2 (GND), U3.2 (GND), U4.4 (FB), U9.1 (GND), U14.2 (GND)
GNDA: C32.1, C34.1, C42.2, C44.2, C47.2, C48.2, C49.2, C56.2, C57.2, C58.2, C59.1, C66.2, C67.2, C68.2, C69.2, C76.2, C84.2, C85.2, C86.1, C87.2, C93.1, C94.1, C95.1, C96.1, J3.1 (EXT), J4.1 (EXT), JP1.2 (B), R13.2, R18.2, R38.2, R39.2, R40.2, R41.2, R57.2, R58.2, U5.9 (AGNDF), U5.11 (AGNDR), U5.16 (AGNDC), U5.19 (AGNDL), U5.24 (DEMP0), U5.25 (DEMP1), U5.27 (FMT1), U12.14 (AGND), U15.3 (+), U15.5 (+)
GNDD: C7.2, C8.2, C9.2, C10.2, C11.2, C14.2, C50.2, C51.2, C52.2, C53.2, C54.2, C55.2, C62.2, C63.2, C79.2, C80.2, C81.2, C82.1, C83.2, C97.2, H1.1, H3.1, J2.2 (GND), J7.16, J7.20, J8.6, J9.3, JP6.2 (B), L18.2, R7.1, R8.1, R29.1, R42.1, R44.1, R45.1, U1.3 (M1), U1.4 (M2), U5.8 (DGND), U6.3 (SDIN/HWM), U6.8 (PGND), U6.18 (DGND), U8.1 (GND), U10.1 (GND), U12.4 (CODE2), U12.5 (DGND), U17.5, U17.7 (GND), U17.9, U17.11, U17.13, Y1.2, Y1.4
MIX_A: C31.1, RV1.1, RV1.2, U15.1, U16.3 (+)
MIX_B: C33.1, RV2.1, RV2.2, U15.7, U16.5 (+)
unnamed: C15.1, L1.1, U1.39 (OUT_A), U1.40 (OUT_A)
unnamed: C21.1, R4.2
unnamed: C22.2, R3.2
unnamed: C24.1, L4.1, U1.27 (OUT_D), U1.28 (OUT_D)
unnamed: C29.2, R5.2
unnamed: C30.1, R6.2
unnamed: C41.1, R9.1, R11.2, R14.2
unnamed: C41.2, R10.1, R12.2, R13.1
unnamed: C43.1, C99.1, R14.1, U7.1
unnamed: C45.1, R15.1, R17.2, R19.2
unnamed: C45.2, R16.1, R18.1, R20.2
unnamed: C46.1, C100.1, R17.1, U7.7
unnamed: C101.1, R47.2, R49.2, R51.2
unnamed: C102.1, R48.2, R50.2, R52.2
unnamed: D1.1 (K), L5.1, U4.2 (OUT)
unnamed: D2.2 (A), U16.1
unnamed: C79.1, D2.1 (K), D3.1 (K), R43.2, R44.2, R46.2, U17.1
unnamed: D3.2 (A), U16.7
unnamed: J7.2, U18.12 (PB0)
unnamed: J7.3, U18.13 (PB1)
unnamed: J7.4, U18.14 (PB2)
unnamed: J7.8, U18.7 (XTAL1/PB6)
unnamed: J7.10, U18.8 (XTAL2/PB7)
unnamed: J7.13, U18.32 (PD2)
unnamed: J7.14, U18.1 (PD3)
unnamed: J7.15, U18.2 (PD4)
unnamed: J7.17, U18.9 (PD5)
unnamed: J7.18, U18.10 (PD6)
unnamed: J7.19, U18.11 (PD7)
unnamed: C64.2, C93.2, JP2.1 (A), R30.2, R31.1, U11.3 (+)
unnamed: C65.1, JP2.2 (B), U11.1, U11.2 (-)
unnamed: C70.2, C94.2, JP3.1 (A), R32.2, R33.1, U11.5 (+)
unnamed: C71.1, JP3.2 (B), U11.6 (-), U11.7
unnamed: C72.2, C95.2, JP4.1 (A), R34.2, R35.1, U13.3 (+)
unnamed: C74.1, JP4.2 (B), U13.1, U13.2 (-)
unnamed: C73.2, C96.2, JP5.1 (A), R36.2, R37.1, U13.5 (+)
unnamed: C75.1, JP5.2 (B), U13.6 (-), U13.7
unnamed: C8.1, U1.14 (AVDD)
unnamed: C15.2, U1.44 (BST_A)
unnamed: C16.2, U1.43 (BST_B)
unnamed: C9.1, U1.15 (C_START)
unnamed: C7.1, U1.11 (DVDD)
unnamed: R8.2, U1.8 (FREQ_ADJ)
unnamed: C12.1, L17.2, U1.1 (GVDD_AB)
unnamed: C31.2, U1.5 (INPUT_A)
unnamed: C32.2, U1.6 (INPUT_B)
unnamed: R7.2, U1.7 (OC_ADJ)
unnamed: C16.1, L2.1, U1.35 (OUT_B)
unnamed: C10.1, U1.20 (VBG)
unnamed: C23.2, U1.24 (BST_C)
unnamed: C24.2, U1.23 (BST_D)
unnamed: C13.1, L19.2, U1.22 (GVDD_CD)
unnamed: C33.2, U1.16 (INPUT_C)
unnamed: C34.2, U1.17 (INPUT_D)
unnamed: C23.1, L3.1, U1.32 (OUT_C)
unnamed: R22.1, U5.2 (BCK)
unnamed: R23.1, U5.3 (DATA)
unnamed: R21.1, U5.1 (LRCK)
unnamed: R24.1, U5.5 (SCK)
unnamed: C44.1, U5.14 (VCOM)
unnamed: C48.1, C49.1, L6.2, U5.7 (VDD)
unnamed: R10.2, U5.17 (VOUTL+)
unnamed: R9.2, U5.18 (VOUTL-)
unnamed: R16.2, U5.13 (VOUTR+)
unnamed: R15.2, U5.12 (VOUTR-)
unnamed: R22.2, U6.14 (BCLK)
unnamed: R26.2, U6.5 (CSB/GP1)
unnamed: R23.2, U6.12 (DOUT)
unnamed: R21.2, U6.15 (LRCK)
unnamed: R24.2, U6.16 (MCLK)
unnamed: C50.1, C51.1, L9.2, U6.7 (PVDD)
unnamed: R27.2, U6.1 (SCLK)
unnamed: R28.2, U6.4 (SDOUT/GP2)
unnamed: C53.1, U6.11 (XIN), Y1.1
unnamed: C54.1, U6.10 (XOP), Y1.3
unnamed: C42.1, R12.1, U7.3 (+)
unnamed: C43.2, R11.1, U7.2 (-)
unnamed: C47.1, R20.1, U7.5 (+)
unnamed: C46.2, R19.1, U7.6 (-)
unnamed: C56.1, C57.1, L8.2, U7.8 (V+)
unnamed: C58.1, C59.2, L7.1, U7.4 (V-)
unnamed: C66.1, L10.2, U11.8 (V+)
unnamed: C67.1, L11.1, U11.4 (V-)
unnamed: R47.1, U12.20 (OUT1)
unnamed: R48.1, U12.19 (OUT2)
unnamed: R49.1, U12.18 (OUT3)
unnamed: R50.1, U12.13 (OUT4)
unnamed: R51.1, U12.12 (OUT5)
unnamed: R52.1, U12.11 (OUT6)
unnamed: C76.1, U12.15 (REF)
unnamed: C68.1, L21.2, U13.8 (V+)
unnamed: C69.1, L20.1, U13.4 (V-)
unnamed: C101.2, RV1.3, U15.2 (-)
unnamed: C102.2, RV2.3, U15.6 (-)
unnamed: C84.1, C87.1, L14.2, U15.8 (V+)
unnamed: C85.1, C86.2, L15.1, U15.4 (V-)
unnamed: R42.2, R43.1, U16.2 (-)
unnamed: R45.2, R46.1, U16.6 (-)
unnamed: C80.1, C83.1, L12.2, U16.8 (V+)
unnamed: C81.1, C82.2, L13.1, U16.4 (V-)
unnamed: U17.2, U17.3
unnamed: C92.2, R56.1, U18.20 (AREF)
unnamed: C88.1, C89.1, C90.1, L16.2, U18.4 (VCC), U18.18 (AVCC)
SCL: R1.2, U12.6 (SCL), U18.27 (PC4)
SDA: R2.2, U12.7 (SDA), U18.28 (PC5)
VDC: C1.1, C2.1, C3.1, C4.1, C5.1, C6.1, C36.1, C39.1, C77.1, J1.1, U1.29 (PVDD_CD), U1.30 (PVDD_CD), U1.31 (PVDD_CD), U1.36 (PVDD_AB), U1.37 (PVDD_AB), U1.38 (PVDD_AB), U2.1 (IN), U4.1 (VIN), U14.1 (IN)

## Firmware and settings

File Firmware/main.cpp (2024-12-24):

#ifndef BOARD_DEFINITION
#error "BOARD_DEFINITION not defined"
#else
#include BOARD_DEFINITION
#endif

#include "lib/Serial.h"
#include "lib/IO.h"
#include "lib/AdvancedIO.h"
#include "lib/I2C.h"
#include "lib/LiquidCrystal.h"
#include "lib/RotaryEncoder.h"
#include "lib/PT2258.h"
#include "lib/Timer.h"
#include "lib/IRReceiver.h"

#include <util/delay.h>
#include <avr/pgmspace.h>
#include <avr/eeprom.h>
#include <avr/sleep.h>

#include "src/Progressbar.h"
#include "src/ChannelSetting.h"

auto lcd = LiquidCrystal::Display(rs, rw, en, d4, d5, d6, d7);
auto pt2258 = PT2258(i2c_bus, 0x88);
auto enc_button = Button(enc_button_pin);
auto encoder = RotaryEncoder(enc_a, enc_b, encoder_stepsize);
auto mute_button = Button(mute_pin);
auto ir_receiver = IR::Receiver(ir_receiver_pin);

auto master_channel = MasterChannelSetting((uint8_t *)0);
auto toslink_channel = SingleChannelSetting("TOSLINK", PT2258::Channel::CHANNEL_1, PT2258::Channel::CHANNEL_2, (uint8_t *)1);
auto line1_channel = SingleChannelSetting("Line 1", PT2258::Channel::CHANNEL_5, PT2258::Channel::CHANNEL_6, (uint8_t *)2);
auto line2_channel = SingleChannelSetting("Line 2", PT2258::Channel::CHANNEL_3, PT2258::Channel::CHANNEL_4, (uint8_t *)3);
ChannelSetting *channels[] = {&master_channel, &toslink_channel, &line1_channel, &line2_channel};

uint8_t current_channel = 0;
bool channel_active = false;
bool is_muted = false;
volatile uint16_t seconds_until_standby = standby_delay_seconds;
volatile uint16_t seconds_until_lightsout = lightsout_delay_seconds;
volatile uint16_t last_mute_action = 0;
volatile bool needs_rerender = false;
volatile IR::Command next_ir_command = IR::Command::UNKNOWN;

enum class DisplayState
{
    POWERON,
    STANDBY,
    LIGHTSOUT
};

enum class AmpState
{
    POWERON,
    FAULT,
    CLIP,
    MUTED,
    POWERDOWN
};

volatile DisplayState display_state = DisplayState::LIGHTSOUT;
volatile AmpState amp_state = AmpState::POWERDOWN;

void reset_timeout_timers()
{
    seconds_until_standby = standby_delay_seconds;
    seconds_until_lightsout = lightsout_delay_seconds;
    seconds_until_lightsout = lightsout_delay_seconds;
    last_mute_action = Timer::now();
}

void set_amp_state(AmpState new_state)
{
    switch (new_state)
    {
    case AmpState::POWERON:
        amp_power.high();
        pt2258.unmute();
        break;
    case AmpState::MUTED:
        amp_power.low();
        pt2258.mute();
        break;
    case AmpState::POWERDOWN:
        amp_power.low();
        pt2258.unmute(); // unmute so we can detect audio
        break;
    case AmpState::CLIP:
        amp_power.low();
        pt2258.mute();
        break;
    case AmpState::FAULT:
        amp_power.low();
        pt2258.mute();
        break;
    }
    amp_state = new_state;
}

void set_display_state(DisplayState new_state)
{
    if (display_state == new_state)
    {
        return;
    }

    switch (new_state)
    {
    case DisplayState::POWERON:
        set_amp_state(AmpState::POWERON);
        lcd_backlight.high();
        lcd.init();
        lcd.display();
        ringlight_bright.high();
        ringlight_dimmed.low();
        needs_rerender = true;
        break;
    case DisplayState::LIGHTSOUT:
        set_amp_state(AmpState::POWERON);
        ringlight_dimmed.high();
        if (display_state == DisplayState::POWERON)
        {
            ringlight_bright.low();
            lcd_backlight.low();
            lcd.no_display();
        }
        else if (display_state == DisplayState::STANDBY)
        {
            seconds_until_standby = standby_delay_seconds;
            Timer::start();
        }
        break;
    case DisplayState::STANDBY:
        if (amp_state != AmpState::CLIP || amp_state != AmpState::FAULT)
        {
            set_amp_state(AmpState::POWERDOWN);
        }
        ringlight_bright.low();
        ringlight_dimmed.low();
        lcd_backlight.low();
        lcd.no_display();

        break;
    }
    display_state = new_state;
}
class : public IO::PinChangeListener
{
    void call() override
    {
        uint8_t has_fault = !amp_fault_pin.read();
        uint8_t is_clipping = !amp_clip_pin.read();
        if (has_fault)
        {
            set_amp_state(AmpState::FAULT);
            needs_rerender = true;
        }
        if (is_clipping)
        {
            set_amp_state(AmpState::CLIP);
            needs_rerender = true;
        }
        if (!has_fault && !is_clipping &&
            (amp_state == AmpState::FAULT || amp_state == AmpState::CLIP))
        {
            auto next_amp_state = is_muted ? AmpState::MUTED : AmpState::POWERON;
            set_amp_state(seconds_until_standby == 0 ? AmpState::POWERDOWN
                                                     : next_amp_state);
            needs_rerender = true;
        }
    }
} fault_listener;

class : public IO::PinChangeListener
{
    void call() override
    {
        if (audio_detect.read())
        {
            if (display_state == DisplayState::STANDBY)
            {
                set_display_state(DisplayState::LIGHTSOUT);
            }
            seconds_until_standby = standby_delay_seconds;
        }
    }
} audio_detect_listener;

class : public IR::CommandListener
{
    void on_receive(IR::Command command)
    {
        next_ir_command = command;
    }
} ir_receiver_listener;

void on_timer_ticked()
{
    if (seconds_until_lightsout > 0)
        if (seconds_until_lightsout > 0)
        {
            seconds_until_lightsout--;
            seconds_until_lightsout--;
        }
        else if (seconds_until_standby > 0)
        {
            set_display_state(DisplayState::LIGHTSOUT);

            if (!audio_detect.read())
            {
                seconds_until_standby--;
            }
        }
        else
        {
            set_display_state(DisplayState::STANDBY);
        }
}

void setup()
{
    Serial::UART::the.init(115200, Serial::Direction::TX_ONLY);
    i2c_bus.init();
    lcd.init();
    load_progressbar_chars(lcd);
    encoder.init();

    amp_clip_pin.pc_port().attach(amp_clip_pin);
    amp_fault_pin.pc_port().attach(amp_fault_pin);
    amp_clip_pin.pc_port().attach_callback(&fault_listener);
    amp_fault_pin.pc_port().attach_callback(&fault_listener);

    audio_detect.pc_port().attach(audio_detect);
    audio_detect.pc_port().attach_callback(&audio_detect_listener);

    ir_receiver.begin(&ir_receiver_listener);

    Timer::init();
    Timer::every(1000, on_timer_ticked);

    for (auto &channel : channels)
    {
        channel->load_saved_volume(pt2258);
    }
    channels[current_channel]->render(lcd, false);
    set_amp_state(AmpState::POWERON);
    set_display_state(DisplayState::POWERON);
}

void loop()
{
    // always make sure the timer is running when we start the loop since we
    // may come from power down mode
    Timer::start();
    // set the sleep mode. this may be overridden while the loop runs if we call
    // enter_standby in the timer callback/
    // SLEEP_MODE_IDLE is the only mode that allows the timer to run
    set_sleep_mode(SLEEP_MODE_IDLE);

    int8_t encoder_delta = encoder.delta();
    if (encoder_delta != 0 || next_ir_command != IR::Command::UNKNOWN)
    {
        reset_timeout_timers();
        set_display_state(DisplayState::POWERON);
        needs_rerender = true;
    }

    // ignore mutliple mute actions within the same second
    bool mute_action_valid = last_mute_action + 1000 < Timer::now();
    if ((mute_button.was_pressed() || next_ir_command == IR::Command::MUTE) && mute_action_valid)
    {
        reset_timeout_timers();
        set_display_state(DisplayState::POWERON);
        is_muted = !is_muted;
        if (is_muted)
        {
            set_amp_state(AmpState::MUTED);
        }
        else
        {
            set_amp_state(AmpState::POWERON);
        }
        needs_rerender = true;
    }

    if (enc_button.was_pressed())
    {
        reset_timeout_timers();
        set_display_state(DisplayState::POWERON);
        channel_active = !channel_active;
        if (!channel_active)
        {
            channels[current_channel]->save_volume();
        }
        needs_rerender = true;
    }

    if (!is_muted && next_ir_command == IR::Command::VOLUME_UP)
    {
        channels[current_channel]->offset_volume(pt2258, 1);
        needs_rerender = true;
    }

    if (!is_muted && next_ir_command == IR::Command::VOLUME_DOWN)
    {
        channels[current_channel]->offset_volume(pt2258, -1);
        needs_rerender = true;
    }

    if (!is_muted && encoder_delta != 0)
    {
        if (channel_active)
        {
            channels[current_channel]->offset_volume(pt2258, encoder_delta);
        }
        else
        {
            uint8_t num_channels = sizeof(channels) / sizeof(channels[0]);
            int new_channel = current_channel + encoder_delta;
            if (new_channel < 0)
            {
                new_channel += num_channels;
            }
            current_channel = new_channel % num_channels;
        }
    }

    if (needs_rerender)
    {
        needs_rerender = false;
        if (amp_state == AmpState::FAULT || amp_state == AmpState::CLIP)
        {
            lcd.clear();
            lcd.set_cursor(0, LiquidCrystal::Row::Second);
            lcd.puts("\x06\x06   FAULT!   \x07\x07");
            return;
        }
        if (amp_state == AmpState::MUTED)
        {
            lcd.clear();
            lcd.set_cursor(0, LiquidCrystal::Row::Second);
            lcd.puts("\x06\x06    Mute    \x07\x07");
            return;
        }

        channels[current_channel]->render(lcd, channel_active);
    }

    next_ir_command = IR::Command::UNKNOWN;
    // sleep for 100 ms, which is a simple way to debounce some stuff
    // (e.g. the encoder updating the pt2258). Since we enter sleep mode
    // right after this, we're ready to wake up again as soon as something
    // (PCINT) happens.
    _delay_ms(100);
    sleep_mode();
}

int main()
{
    setup();
    while (1)
    {
        loop();
    }
}

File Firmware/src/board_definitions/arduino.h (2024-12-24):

#pragma once

#include "lib/IO.h"
#include "lib/AdvancedIO.h"
#include "lib/I2C.h"

auto rs = IO::Output(IO::Port::PortB, 0);
auto rw = IO::Output(IO::Port::PortB, 1);
auto en = IO::Output(IO::Port::PortB, 2);
auto d4 = IO::Output(IO::Port::PortD, 4);
auto d5 = IO::Output(IO::Port::PortD, 5);
auto d6 = IO::Output(IO::Port::PortD, 6);
auto d7 = IO::Output(IO::Port::PortD, 7);
const auto lcd_backlight = IO::Output(IO::Port::PortB, 5);

const auto ringlight_bright = IO::Output(IO::Port::PortC, 4);
const auto ringlight_dimmed = IO::Output(IO::Port::PortC, 4);
const auto amp_power = IO::Output(IO::Port::PortC, 2);
const auto audio_detect = IO::PinChangeInterruptPin(IO::PinChangeInterruptPort::PortC, 0, IO::PullupMode::Disable);
const auto ir_receiver_pin = IO::PinChangeInterruptPin(IO::PinChangeInterruptPort::PortD, 0, IO::PullupMode::Disable);

auto enc_a = IO::PinChangeInterruptPin(IO::PinChangeInterruptPort::PortC, 4, IO::PullupMode::Enable);
auto enc_b = IO::PinChangeInterruptPin(IO::PinChangeInterruptPort::PortC, 3, IO::PullupMode::Enable);
auto enc_button_pin = IO::PinChangeInterruptPin(IO::PinChangeInterruptPort::PortC, 5, IO::PullupMode::Enable);

auto mute_pin = IO::PinChangeInterruptPin(IO::PinChangeInterruptPort::PortC, 2, IO::PullupMode::Enable);
auto amp_fault_pin = IO::PinChangeInterruptPin(IO::PinChangeInterruptPort::PortC, 1, IO::PullupMode::Enable);
auto amp_clip_pin = IO::PinChangeInterruptPin(IO::PinChangeInterruptPort::PortC, 1, IO::PullupMode::Enable);

const I2C::Master &i2c_bus = I2C::HardwareMaster::the;

constexpr uint8_t encoder_stepsize = 2;
constexpr uint16_t standby_delay_seconds = 30;
constexpr uint16_t lightsout_delay_seconds = 5;

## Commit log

2024-02-09 initial commit with current state
    [ATS-CPX-197-CX-R0_FUSED.STEP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]
2024-02-10 more IO drivers for the Firmware
2024-02-10 implement step size handling for rotary encoder driver
2024-02-12 add PT2257 driver and proper interrupt driven duttons
2024-02-27 firmware with most functions and real pin definitions
2024-02-28 firmware revision for real hardware
    [AmplifierBoard.kicad_pcb]
2024-03-04 updated schematic of amplifier board
    [AmplifierBoard.kicad_pcb, AmplifierBoard.kicad_sch, AudioDetect.kicad_sch]
2024-03-04 move to soft i2c implementation due to wiring mshap
2024-03-09 add master mix functionality to PT2258 driver
2024-03-09 fixe standby reset logic on audio detect
    [main.cpp]
2024-12-23 update pcb version
    [AmplifierBoard.kicad_sch, AnalogBuffers.kicad_sch, AudioDetect.kicad_sch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]
2024-12-23 fix i2c driver
